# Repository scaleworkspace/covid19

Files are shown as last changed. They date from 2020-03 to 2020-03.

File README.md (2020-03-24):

# Scale Workspace Response to COVID19
In the span of four months, the Coronavirus has become an international pandemic. Since March 8th, over 114 cases have been reported in Louisiana with a high concentration in the Greater New Orleans area. As the spread of COVID-19 increases, this virus has a profound and lasting impact on local businesses, healthcare providers, and the community itself.

Despite these setbacks, Scale Workspace and their tenants have stepped up to help flatten the curve. As a New Orleans co-working space focused on product development, rapid manufacturing, and design services, Scale Workspace’s mission is creating innovative products through community assets.

Scale Workspace, Robert Forbes 3D, Entrescan and the New Curiosity Shop have been working on the following initiatives to assist with the local response to the COVID-19 pandemic:

## Medical Initiatives:
With the assistance of the [National Center for Advanced Manufacturing (NCAM)](https://lsu.edu/ncam/), our team has been prototyping Personal Protection Equipment (PPE) for Ochnser Health Systems in anticipation of shortages of critical equipment such as:

1) Masks / respirators

2) Face shields / eye guards

3) Ventilators

Our progress is detailed below, and all of our files will be available on our Github page. If you would like to provide assistance or require our services, please reach out to contact@scaleworkspace.com. 

## DISCLAIMER
Please read this. This is important. We are a community of individuals responding to a community in need. We are providing files and information that we believe will help. Please use this information and these files in the spirit in which they were created: to help, to do good.  

Any information or files provided by Scale Workspace, Entrescan, Robert Forbes 3D, or the New Curiosity Shop (“we,” “us” or “our”) on this github repository or other websites (the “Sites”) is for general informational purposes only. All information and files on the Sites are provided in good faith, however we make no representation or warranty of any kind, express or implied, regarding the accuracy, adequacy, validity, reliability, availability or completeness of any files or information on the Sites for any specific medical purpose.

Under no circumstance shall we have any liability to you for any loss or damage of any kind incurred as a result of the use of the Sites or reliance on any information provided on the Sites. Your use of the Sites and your reliance on any information or files hosted on the Sites is solely at your own risk.

## Daily Updates
### 3-20-2020

We’ve updated files on our Github page for the disposable mask and face shield, including a face shield file ideal for using on a CNC router. Robert Forbes 3D is also working with a regional supplier to make 500 face shields for delivery next week. We received feedback from the Ochsner team about the ventilator and are working on an update to allow two people to use 1 ventilator to mimic a hospital environment where only two patients will be in a room.

### 3-19-2020
Delivered 50 face shields to Ochsner. A product designer reached out about printing a component that allows 4 people to use 1 ventilator, which is now available on our Github page. We’re printing a prototype of that component for Ochsner to use tomorrow (3-20-2020). We’re also working actively with local partners such as Good Wood NOLA to produce large quantities of face shields for Ochsner and other entities who are in need.

### 3-18-2020
Uploaded files for [Face Shield Frame v2](https://github.com/scaleworkspace/covid19/tree/master/Face%20Shield/FaceShieldV2.1), which includes .stl, .step, .dxf, and renderings. There is also ReadMe instructions for the files.

### 3-17-2020
Uploaded files for [Respirator Style Mask](https://github.com/scaleworkspace/covid19/tree/master/DisposableMask?raw=true), [Disposable Mask](https://github.com/scaleworkspace/covid19/tree/master/DisposableMask?raw=true), and [Eye Shield](https://github.com/scaleworkspace/covid19/tree/master/EyeShield?raw=true).

We also purchased materials to help us produce a short run of disposable goods for Ochsner. The files we are using will be available online through our Github repository. We are currently working on a mask design with replaceable filters that should be available on Thursday.

### 3-16-2020 
Created prototypes of face shields and mask and submitted a face shield design to Ochsner for review.

Shield: [][cc-by]

This work is licensed under a [Creative Commons Attribution 4.0 International
License][cc-by].

[][cc-by]

[cc-by]: http://creativecommons.org/licenses/by/4.0/
[cc-by-image]: https://i.creativecommons.org/l/by/4.0/88x31.png
[cc-by-shield]: https://img.shields.io/badge/License-CC%20BY%204.0-lightgrey.svg

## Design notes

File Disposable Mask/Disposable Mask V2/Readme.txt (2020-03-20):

Instructions	

Print (2) of each .stl file attached:"Disposable Mask Top Rev 2" and "Disposable Mask Bottom Rev 2"

Cut a 7.5”x 5” piece of cotton T shirt or use the .dxf provided to lasercut

Clasp P1 and P2 together on either side of the cloth along the 5" edge

Use (2) Rubber bands to loop inside open holes and around your ears, covering your mouth and nose

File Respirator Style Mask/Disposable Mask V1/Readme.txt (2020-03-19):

Instructions	

Print 1 "Respirator Style Mask.stl" at .2mm Layer height in any available material

Cut a 4”x 4” piece of cotton T shirt or use the .dxf provided to lasercut

Use a rubber band to secure the cotton to the mask using the groove provided

You may double or triple the layers of cotton if you'd like

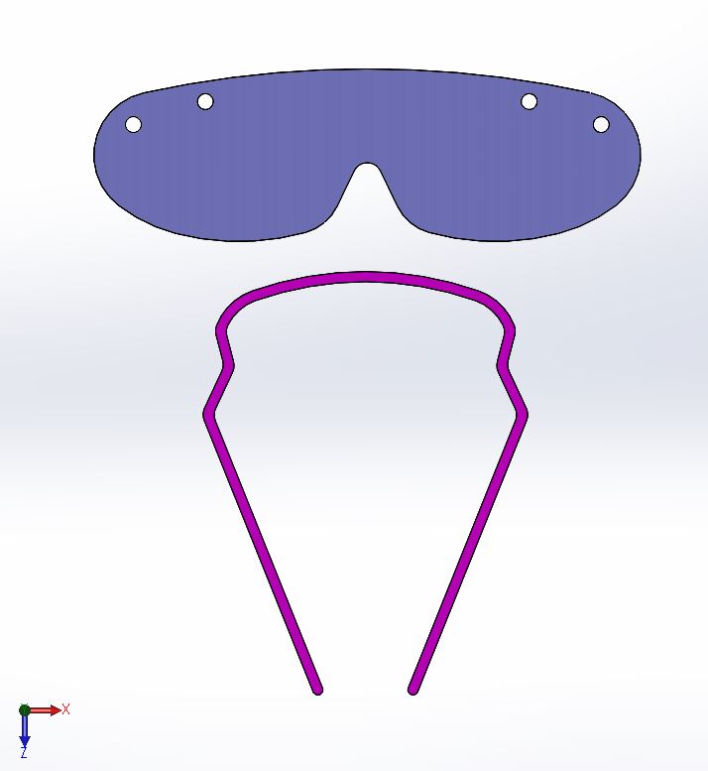
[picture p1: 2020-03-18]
Eye Shield/Eye Shield V1/Eye Shields.JPG

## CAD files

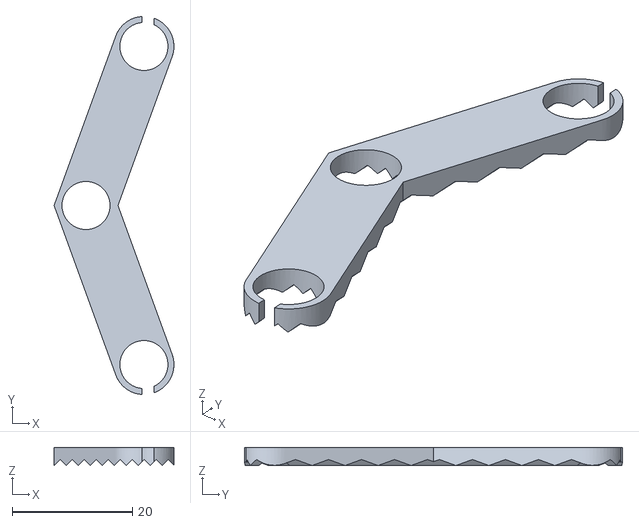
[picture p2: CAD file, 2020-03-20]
Disposable Mask/Disposable Mask V2/Disposable Mask Top Rev 2.stl
20.0 x 62.9 x 3.01

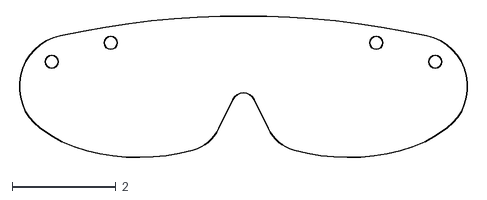
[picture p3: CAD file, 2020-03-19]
Eye Shield/Eye Shield V1/Eye Shield Lens V1.DXF
8.75 x 2.77

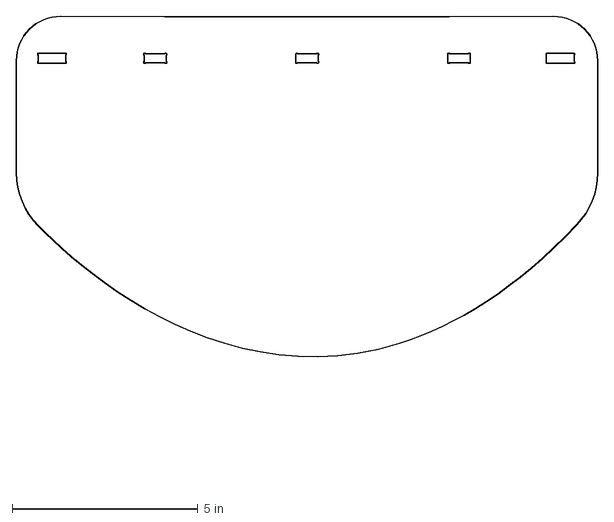
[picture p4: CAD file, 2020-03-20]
Face Shield/Face Shield V4.1 Router/Face Shield (Shield) V4.1.dxf
15.7 x 12.5 in

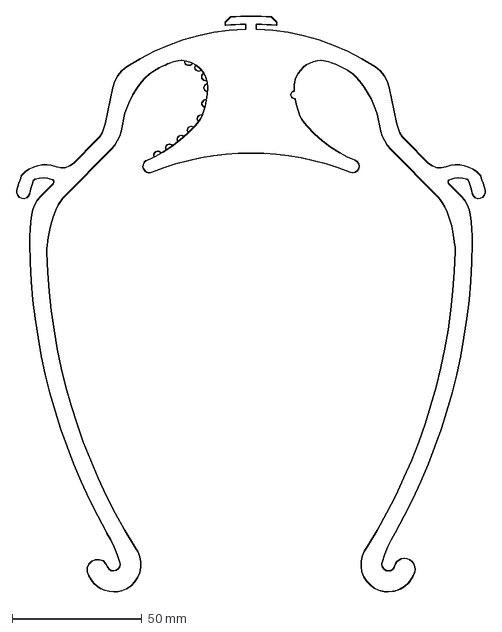
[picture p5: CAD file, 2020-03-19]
Face Shield/Face Shield V4/Face Shield (Frame) V4 Master.dxf
180.8 x 221.4 mm

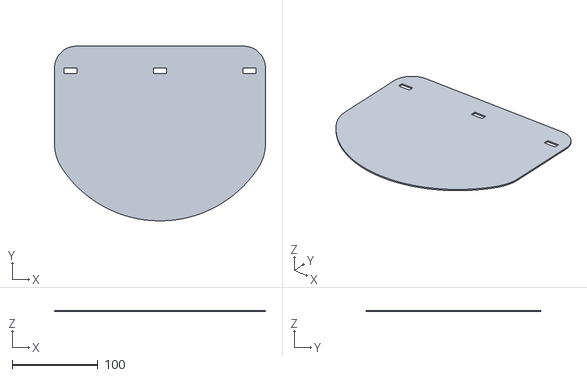
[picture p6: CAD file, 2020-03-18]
Face Shield/Face_Shield_V2/Face_Shield_V2 v1.stl
245.4 x 203.2 x 1.59

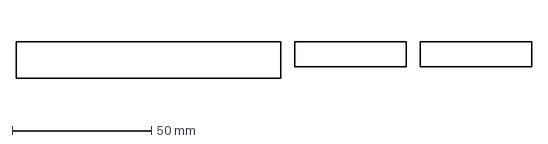
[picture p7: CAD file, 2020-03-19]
Face Shield/FullFaceShield_V3/Foam Cut.dxf
185.0 x 13.0 mm

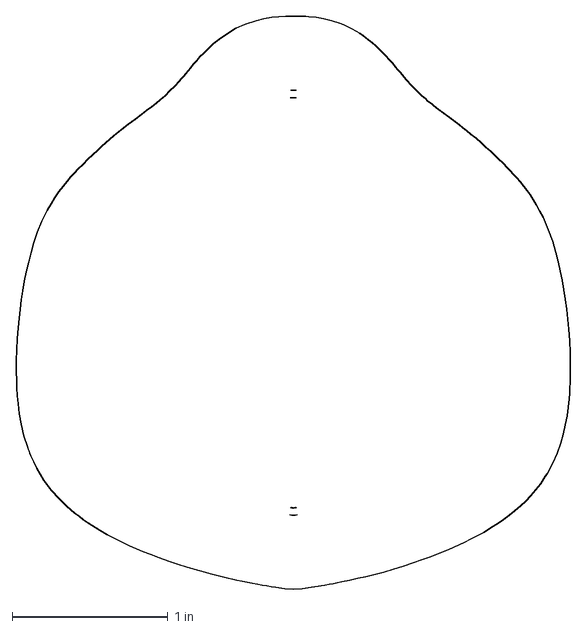
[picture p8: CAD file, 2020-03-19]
Respirator Style Mask/Disposable Mask V1/Mask_Cloth_filter.dxf
3.56 x 3.68 in

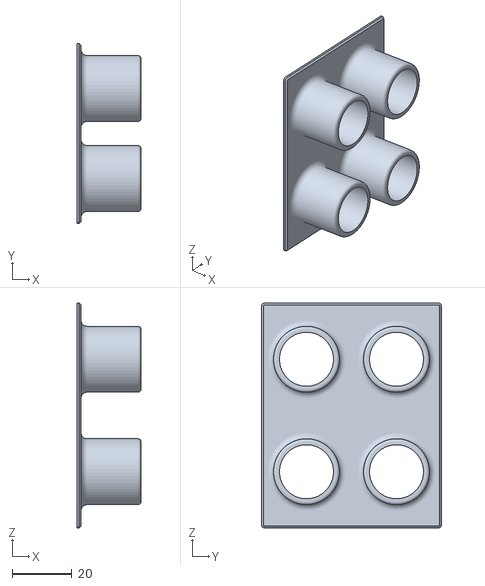
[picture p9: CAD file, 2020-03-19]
Ventilator_Assembly/Toptubes.stl
21.4 x 60.0 x 75.0

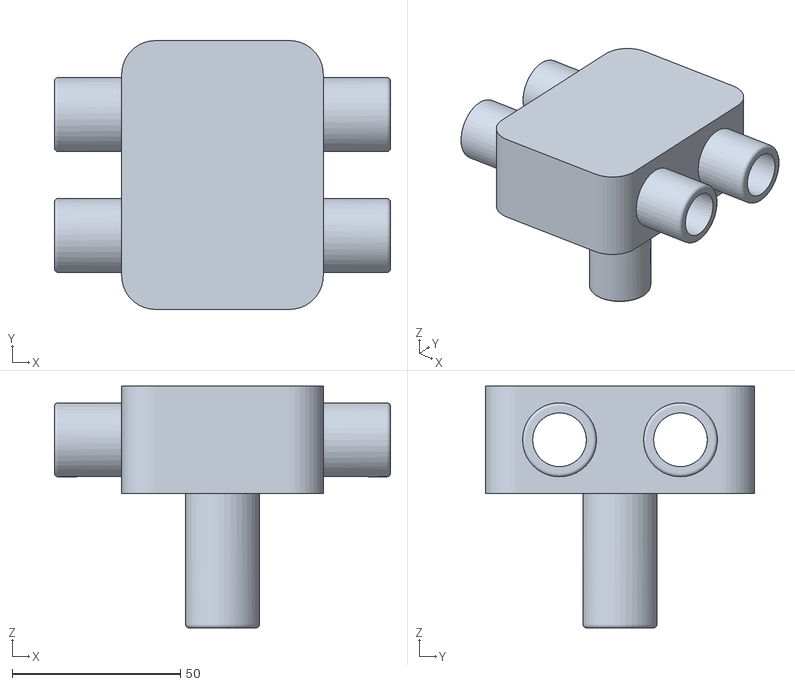
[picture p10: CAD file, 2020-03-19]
Ventilator_SinglePart/Version 2.STL
100.0 x 80.0 x 72.0

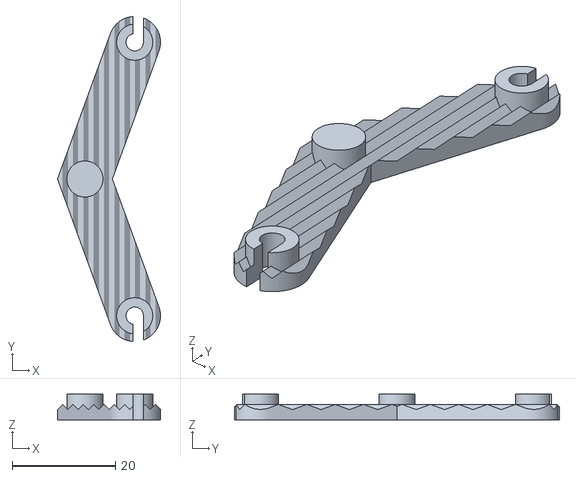
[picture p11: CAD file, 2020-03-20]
Disposable Mask/Disposable Mask V2/Disposable Mask Bottom Rev 2.stl
20.0 x 62.9 x 5.00

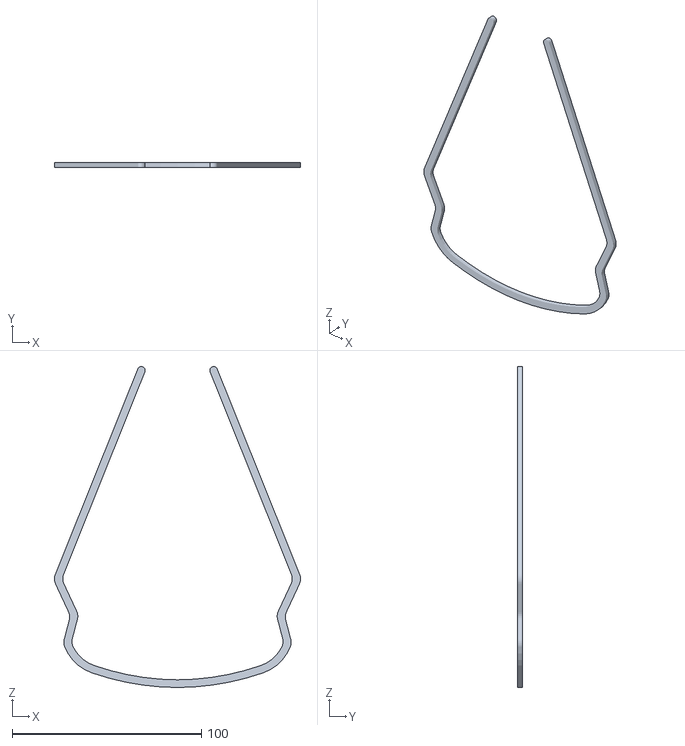
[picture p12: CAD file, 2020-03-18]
Eye Shield/Eye Shield V1/Eye Shield Head Band V1.STL
129.9 x 2.54 x 169.5

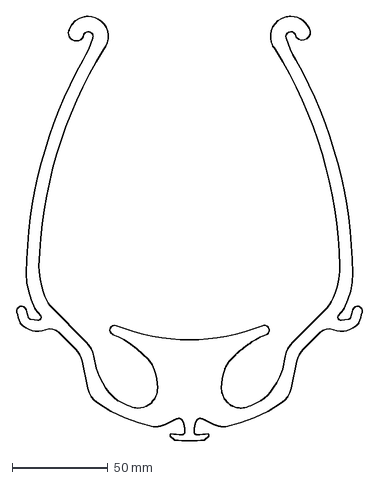
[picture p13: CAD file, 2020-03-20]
Face Shield/Face Shield V4.1 Router/Face Shield (Frame) V4.1.dxf
180.8 x 221.4 mm

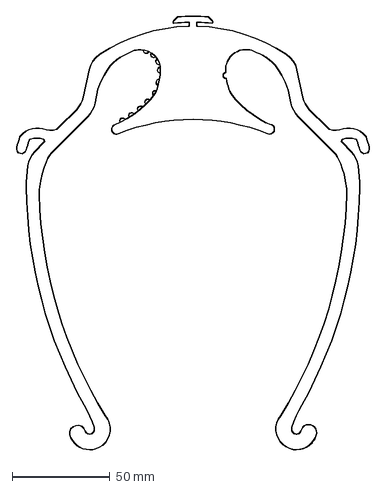
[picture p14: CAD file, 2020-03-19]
Face Shield/Face Shield V4/Face Shield V4 Master.dxf
180.8 x 221.4 mm

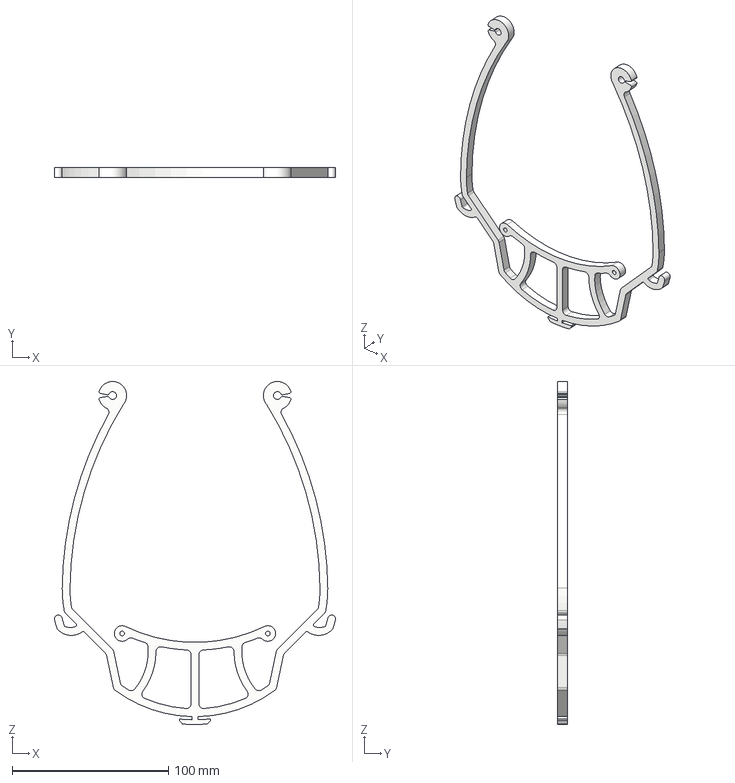
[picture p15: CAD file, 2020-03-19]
Face Shield/FullFaceShield_V3/Face Shield Frame V3.step
180.2 x 6.10 x 219.8 mm

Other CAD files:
Ventilator_Assembly/Plug.stl
Ventilator_SinglePart/Pipe Connector.STL
Disposable Mask/Disposable Mask V2/Disposable Mask.dxf
Face Shield/Face Shield V4/Face Shield (Shield) V4 Master.dxf
Disposable Mask/Disposable Mask V1/Coronamask_P1.stl
Disposable Mask/Disposable Mask V1/Coronamask_P2.stl
Disposable Mask/Disposable Mask V1/Disposable Mask.dxf
Eye Shield/Eye Shield V1/Eye Shield Head Band V1.DXF
Face Shield/FaceShieldV2.1/Face Shield Frame V2.1.dxf
Face Shield/FaceShieldV2.1/Face Shield Frame V2.1.step
Face Shield/FaceShieldV2.1/Face Shield Frame V2.1.stl
Face Shield/FaceShieldV2.1/Face Shield V2.1.dxf
Face Shield/FaceShieldV2.1/Full_Face_Shield_2.1.f3d
Face Shield/Face_Shield_V2/Face_Shield_V2.f3d
Face Shield/FullFaceShield V1/Body2.stl
Face Shield/FullFaceShield V1/Body3.stl
Face Shield/FullFaceShield V1/Full_Face_Shield_2.f3d
Face Shield/FullFaceShield_V3/Face Shield Frame V3.dxf
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

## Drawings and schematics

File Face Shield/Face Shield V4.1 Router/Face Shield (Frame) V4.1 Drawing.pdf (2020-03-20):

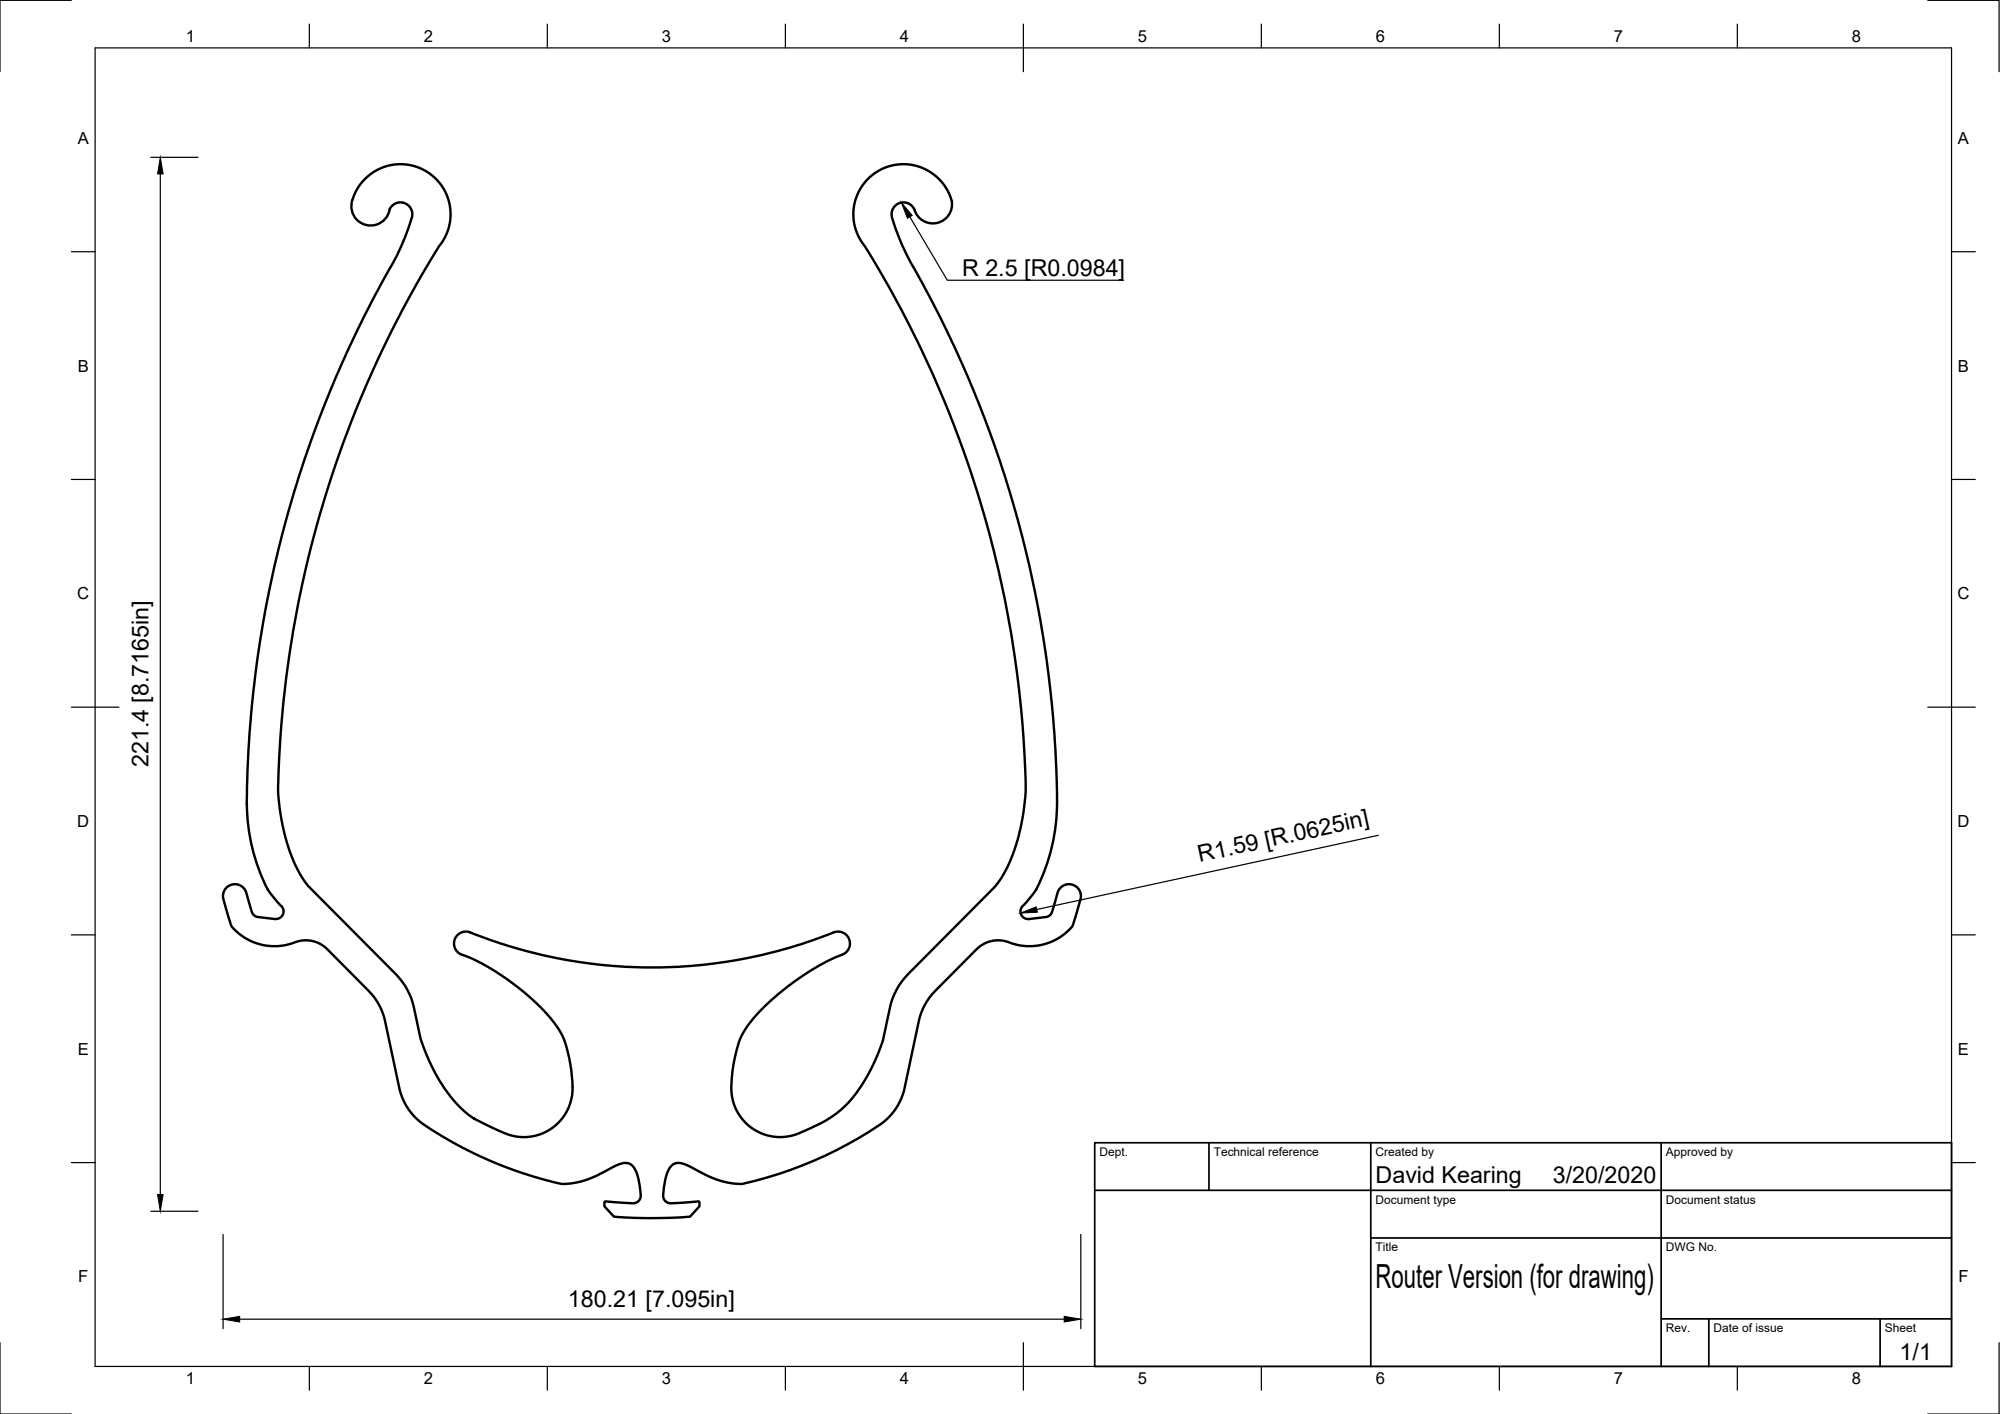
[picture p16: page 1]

Dept. | Technical reference | Created by David Kearing 3/20/2020 | Approved by

Document type | Document status

Title Router Version (for drawing) | DWG No.

Rev. | Date of issue | Sheet 1/1

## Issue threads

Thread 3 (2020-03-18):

Can we get stl files just of the frame itself?

togakangaroo, 2020-03-18:
for example I don't really know fusion 360 so I can't really create it

scaleworkspace, 2020-03-18:
working on this right now. thanks for the heads up @togakangaroo

scaleworkspace, 2020-03-18:
done.

Closed 2020-03-18.

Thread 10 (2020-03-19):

FullFaceShield_V3 Hole Sizes

aheyne, 2020-03-19:
Having trouble getting the pad inserts in with the current hole sized. Have to ream the forehead pad with a 1/8" drill bit and a 13/16th one for the side pads.

Could we just integrate the pads into the design? Would make printing and remove the assembly step and risk of breaking during assembly.

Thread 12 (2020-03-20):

Disposable Mask V1 much too big

ReflexiveCode, 2020-03-20:
STL files are loading as approx 550mm (21 inches) long. What are correct dimensions?

dkearingES, 2020-03-20:
Sorry for this issue. I'm not sure where the sizing was messed up. We have a new version that is up now. If you would, please test that one for me and let me know if things look good.

Thank you for your feedback!

ReflexiveCode, 2020-03-20:
V2 looks good (V1 still too big, not sure if that one is still recommended).

dkearingES, 2020-03-20:
I've just updated V1 and it should be fixed. V2 should also be a slightly better fit/ more secure attachment. We are also working on a smaller simpler version as well now

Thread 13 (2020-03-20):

Feedback on first print of Ventilator_SinglePart

scaleworkspace, 2020-03-20:
The pieces all meet specs. The big issues are that the design doesn't give any room for the tolerance. The cap and the pipe it fits into are both 16mm diameter. As well while I can remove the interior supports, it's not pretty and I worry regarding any loose material that might end up stuck in there that could break free while in use

scaleworkspace, 2020-03-20:
The large enclosed ventilator piece has excess water left in it as you can see from the photo. As well I think we'd do better to move onto the assembled version since we wouldn't need to print interior supports. However we'd need a way to seal it and I don't think we've got any medical grade glues or sealants.

stephenflashtech, 2020-03-20:
Thanks for the update.  The plugs need to be made slightly smaller?  can you let me know what the tolerance should be?  Also can you send me images images of the interior supports?

scaleworkspace, 2020-03-20:
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

scaleworkspace, 2020-03-20:
Let's get feedback from the Ochsner doc before we provide info that we are guessing about re: tolerances.

stephenflashtech, 2020-03-20:
That sounds good.  I do have the other design that might be the best of both worlds or can be adapted to this.
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

stephenflashtech, 2020-03-20:
I sealed this with silicone in the channels.  We could adapt the 2 piece design to have one side slide on.  The 2 piece design would be necessary if I can successfully make the  the butterfly valve version as you would need to get into the device to install the pieces.  Let me know your thoughts on this.  I also have

stephenflashtech, 2020-03-20:
I have sent these to Monark to print.   Here are two new cap designs,  one is 15.5 mm giving us a .5mm tolerance  and one that is 15mm giving us a 1 mm tolerance
[New Caps.zip](https://github.com/scaleworkspace/covid19/files/4361627/New.Caps.zip)

nimamoslemy, 2020-05-03:
Hi, we are a team that needs your feedback to complete our idea.
Please visit our pages and comment on it.
[github](https://github.com/nimamoslemy/ventilator)
[gitlab](https://gitlab.com/nimamoslemy/avp-ventilator)

stephenflashtech, 2020-05-04:
Nima,

send me an email directly and we can chat.  stephen@flashtechusa.com

On Sun, May 3, 2020 at 9:39 AM Nima Moslemy <notifications@github.com>
wrote:

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

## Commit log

2020-03-18 created directory structure and unzipped files
    [Disposable Mask P1.stl, Disposable Mask P2.stl, Disposable Mask.dxf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]
2020-03-18 uploaded STL files for directories that only had fusion 360 files
    [Body2.stl, Body3.stl, Face_Shield_V2 v1.stl]
2020-03-18 added FullFaceShield_V3 files
    [Face Shield Frame V3.dxf, Face Shield Frame V3.step, Face Shield Frame V3.stl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]
2020-03-19 Reorganized Files
    I reorganized the files into 4 main designs and put Versions in their own folder
    [Body2.stl, Body3.stl, Disposable Mask P1.stl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]
2020-03-19 creatd ventilator directories and added files from Stephen Gordon
    [BottomTube.stl, Cap.STL, MiddleVent.stl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]
2020-03-19 Update Face Shield Frame V3 Readme.txt
2020-03-19 V4 Uploaded
    V4 Master and Vendor Versions 1-10 uploaded
    [Face Shield V4 Master.dxf, Face Shield V4 Vendor1.dxf, Face Shield V4 Vendor10.dxf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]
2020-03-19 Create Face Shield V4 Master.dxf
    [Face Shield V4 Master.dxf]
2020-03-19 V4
    Take down V4 vendor versions, copy V3 shield to V4
    [Face Shield (Frame) V4 Master.dxf, Face Shield (Shield) V4 Master.dxf]
2020-03-19 Update Face Shield (Frame) V4 Master.dxf
    [Face Shield (Frame) V4 Master.dxf]
2020-03-19 removed Vendor files
    [Face Shield V4 Vendor1.dxf, Face Shield V4 Vendor10.dxf, Face Shield V4 Vendor2.dxf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]
2020-03-20 Upload Disposable Mask V2
    V2 Uploaded
    [Disposable Mask Bottom Rev 2.stl, Disposable Mask Top Rev 2.stl, Disposable Mask.dxf]
2020-03-20 update V1 disposable to correct size, add face shield 4.1
    [Coronamask_P1.stl, Coronamask_P2.stl, Disposable Mask Bottom Rev 2.stl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]

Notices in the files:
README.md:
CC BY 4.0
